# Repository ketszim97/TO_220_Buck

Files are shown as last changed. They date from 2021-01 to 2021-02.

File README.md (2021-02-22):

# TO_220_Buck
A buck converter drop in replacement for TO-220 LDOs

There are currently two versions:
- One for [78xx series LDOs](https://github.com/ketszim97/TO_220_Buck/tree/78xx)
- One for the [LM1117 LDO](https://github.com/ketszim97/TO_220_Buck/tree/LM1117)

They are both configured for 3.3V, but replacing R3 allows the output voltage to be set. 

|Output Voltage |  R3 Value |
| :---: | :---: |
| 1.5V | 86k6 |
| 1.8V | 60k4 |
| 2.5V | 35k7 |
| 3.3V | 24k3 |
| 5.0V | 14k3 |
| 12V | 5k36 |
| 24V | 2k61 |

Please take note of the pinouts as seen in the renders. 

I've been able to test basic functionality of both boards, but I am currently working on extended testing.

# [LM1117 Version](https://github.com/ketszim97/TO_220_Buck/tree/LM1117)
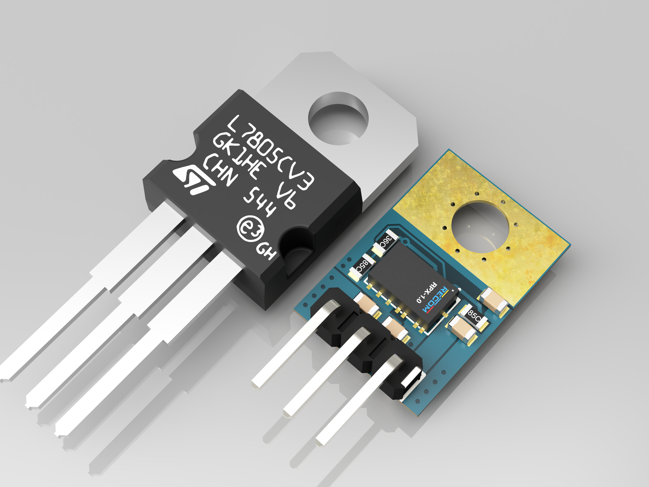
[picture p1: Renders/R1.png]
Fusion Render 1

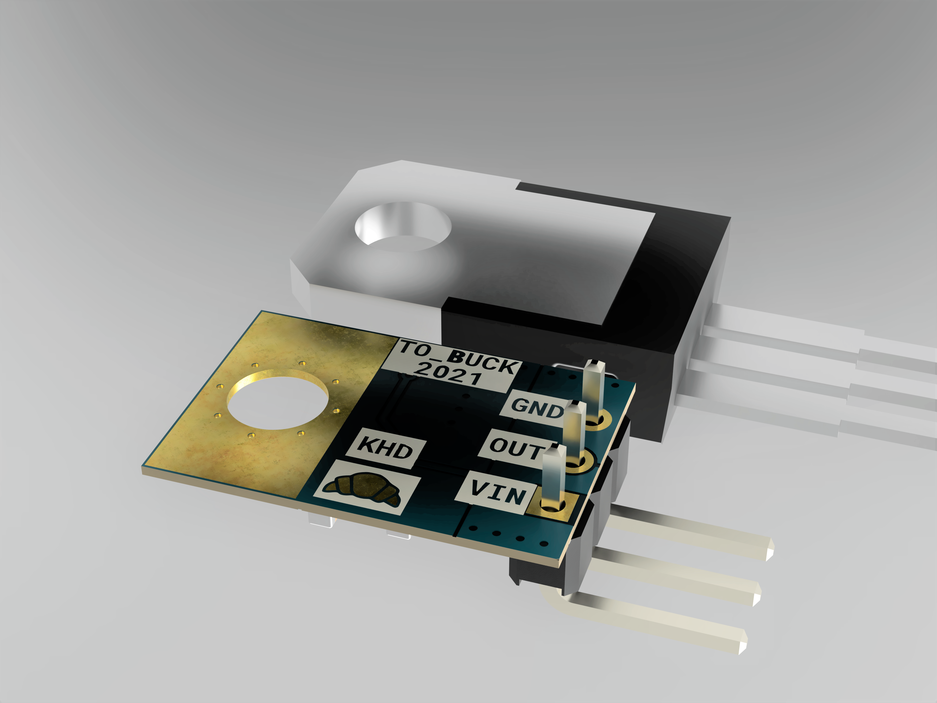
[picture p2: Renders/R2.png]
Fusion Render 2

Fusion Render 2

# [78xx Version](https://github.com/ketszim97/TO_220_Buck/tree/78xx)
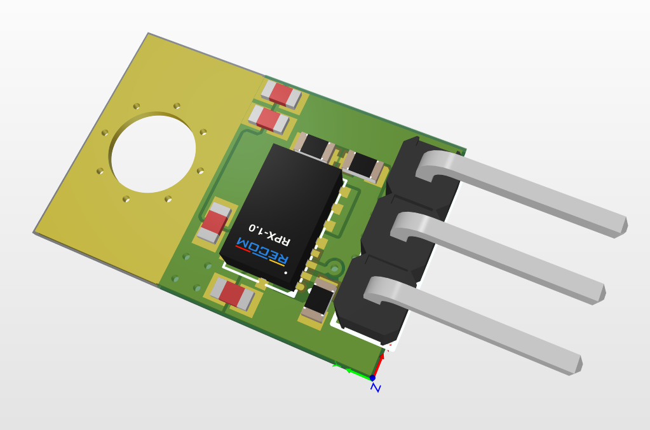
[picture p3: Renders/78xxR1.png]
Fusion Render 1

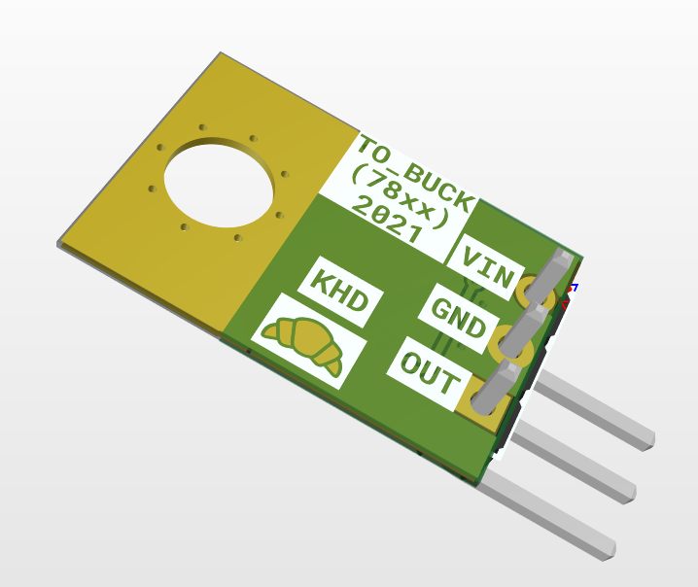
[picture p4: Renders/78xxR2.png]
Fusion Render 2


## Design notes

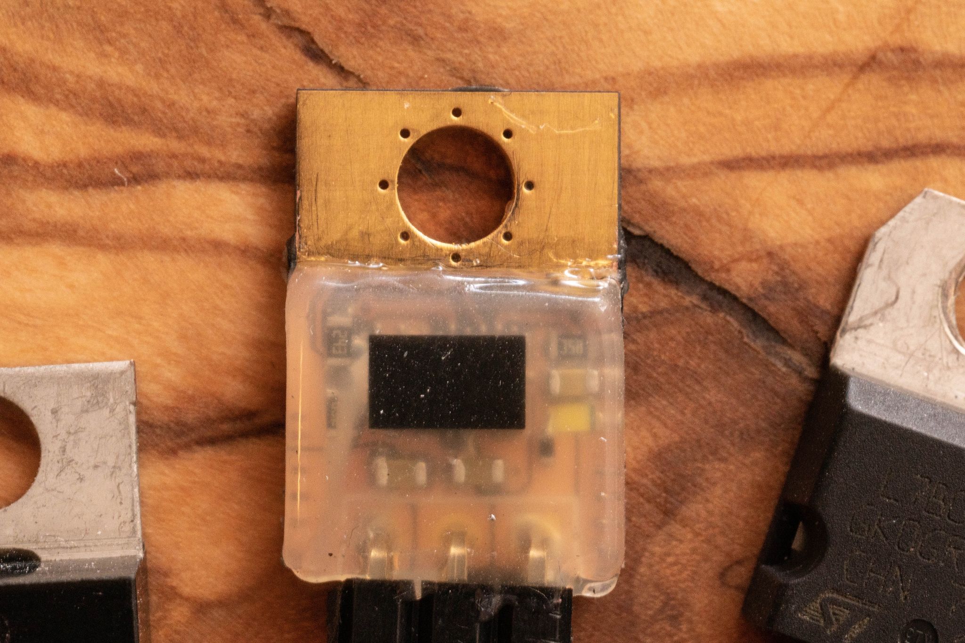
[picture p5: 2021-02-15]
Renders/Photos/149531206_1899397426883809_2604627616475933184_n.jpg

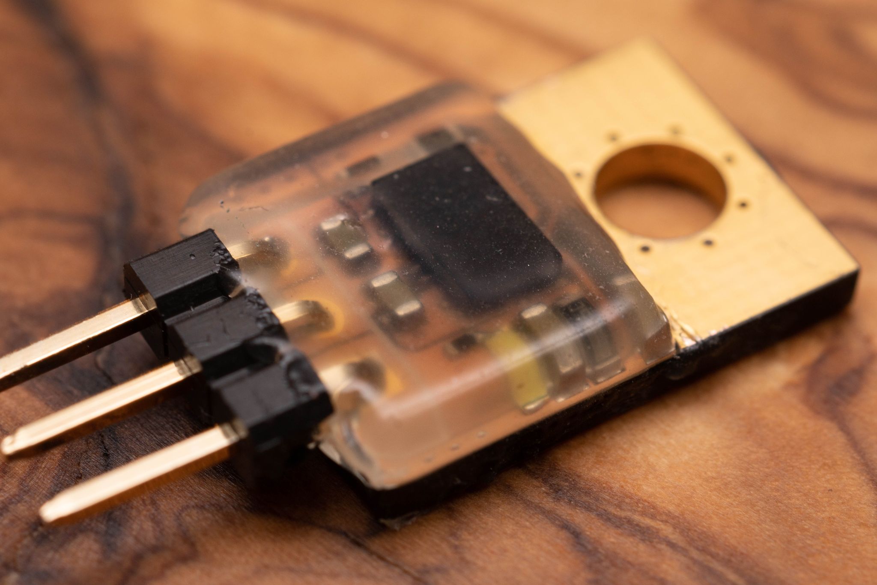
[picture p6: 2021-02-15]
Renders/Photos/149554997_872922463279282_781366280616274840_n.jpg

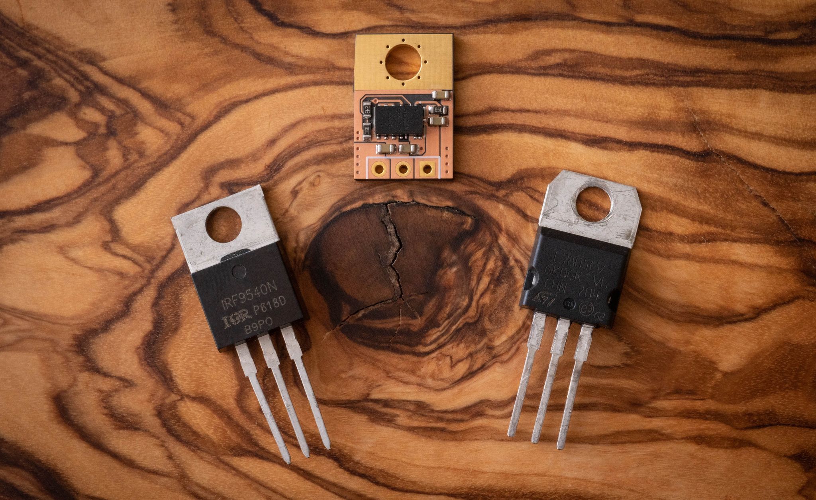
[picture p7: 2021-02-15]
Renders/Photos/150078867_431702474816400_1116094828932131625_n.jpg

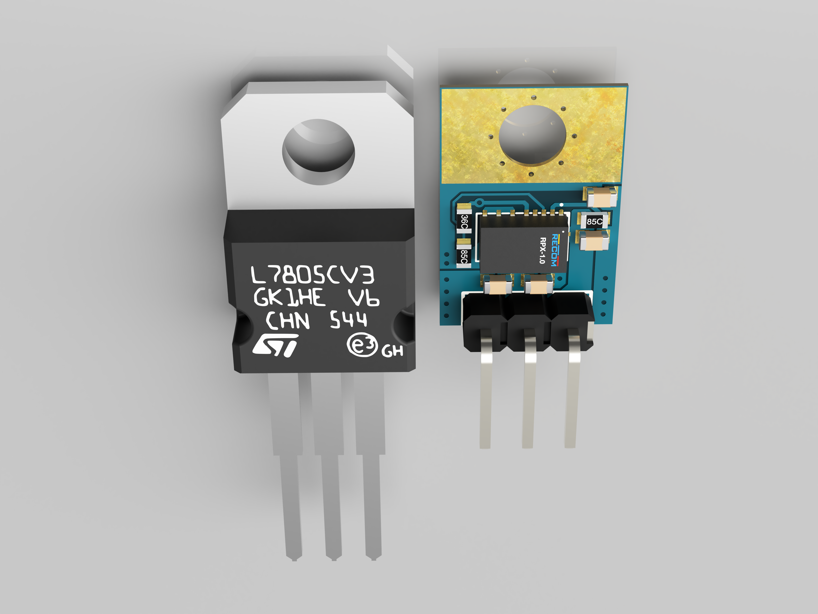
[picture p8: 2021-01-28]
Renders/R3.png

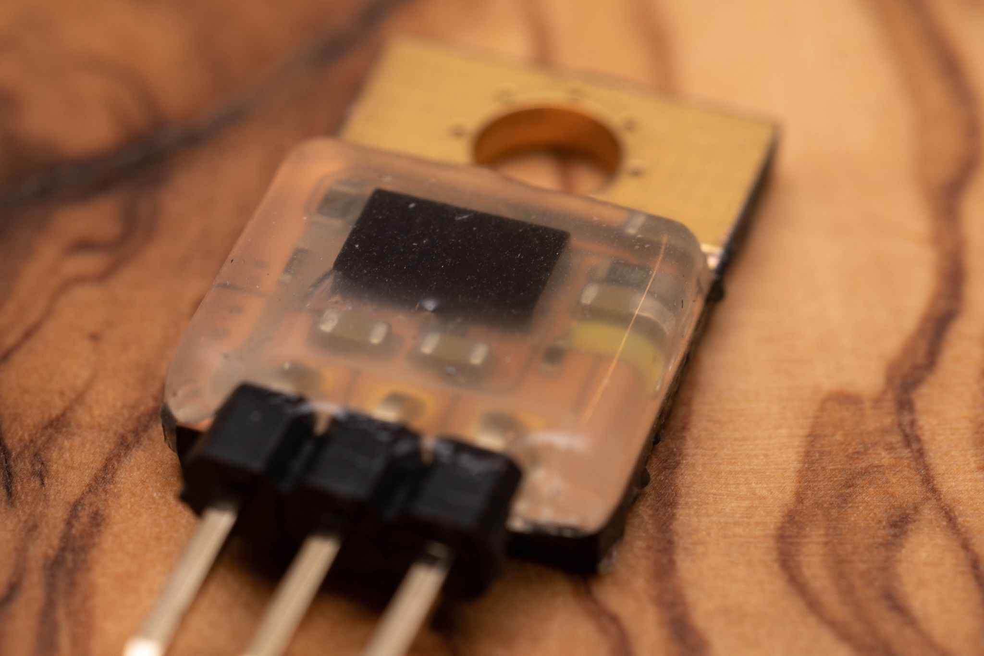
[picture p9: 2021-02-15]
Renders/Photos/149988475_1209948119421982_8042083003570764033_n.jpg

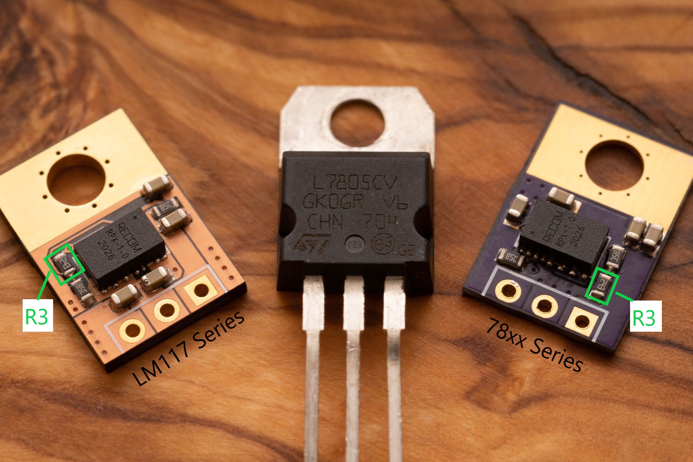
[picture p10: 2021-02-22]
Renders/Photos/R3 Annotation.jpg

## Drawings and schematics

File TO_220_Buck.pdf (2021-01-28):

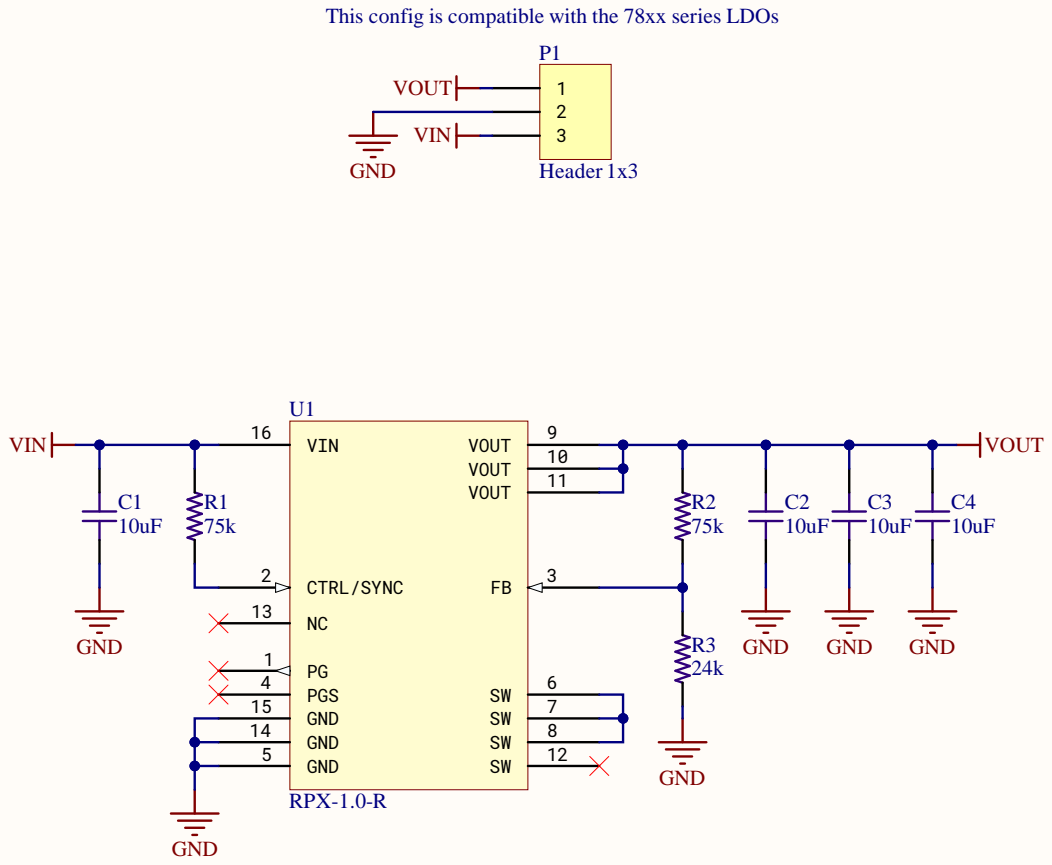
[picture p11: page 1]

This config is compatible with the 78xx series LDOs

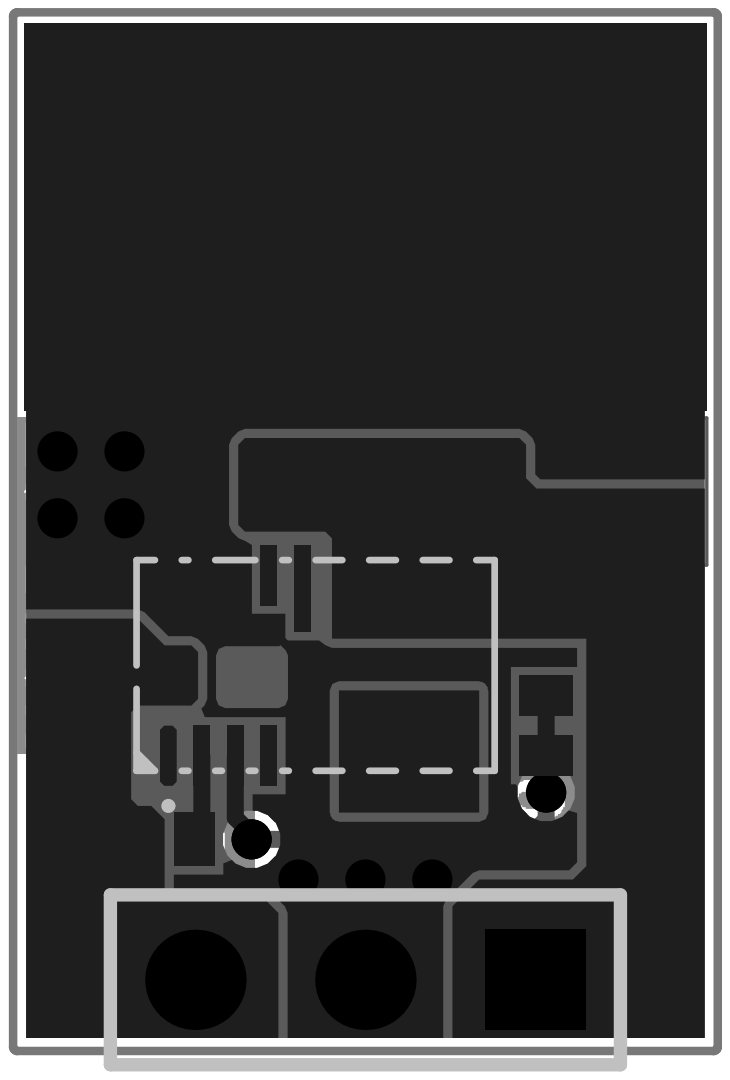
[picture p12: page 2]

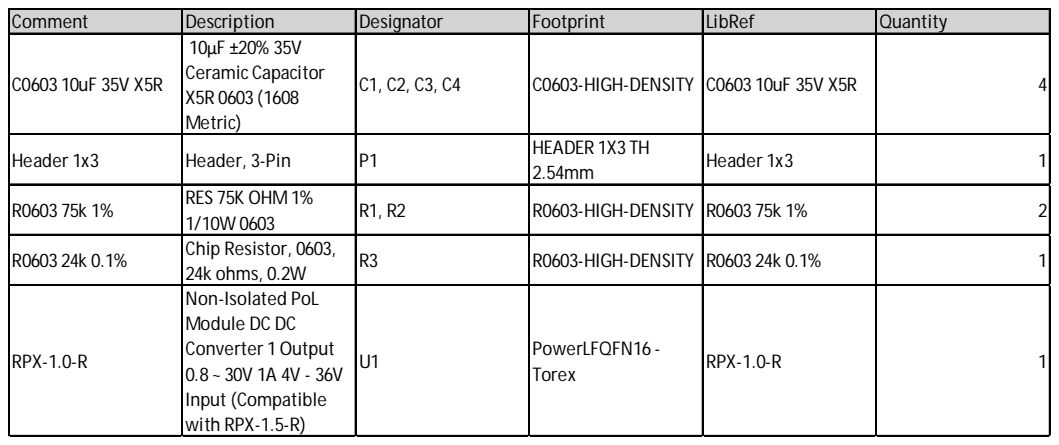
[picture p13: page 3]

Comment | Description | Designator | Footprint | LibRef | Quantity
C0603 10uF 35V X5R | 10µF ±20% 35V Ceramic Capacitor X5R 0603 (1608 Metric) | C1, C2, C3, C4 | C0603-HIGH-DENSITY | C0603 10uF 35V X5R | 4

Header 1x3 | Header, 3-Pin | P1 | HEADER 1X3 TH 2.54mm | Header 1x3 | 1

R0603 75k 1% | RES 75K OHM 1% 1/10W 0603 | R1, R2 | R0603-HIGH-DENSITY | R0603 75k 1% | 2

R0603 24k 0.1% | Chip Resistor, 0603, 24k ohms, 0.2W | R3 | R0603-HIGH-DENSITY | R0603 24k 0.1% | 1

RPX-1.0-R | Non-Isolated PoL Module DC DC Converter 1Output 0.8 ~ 30V 1A 4V - 36V Input (Compatible with RPX-1.5-R) | U1 | PowerLFQFN16 -Torex | RPX-1.0-R | 1

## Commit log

2021-01-28 Initil commit for LM1117 compatible version
    [TO_220_Buck.GBL, TO_220_Buck.GBO, TO_220_Buck.GBP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]
2021-01-28 78xx compatible version
    [TO_220_Buck.GBL, TO_220_Buck.GBO, TO_220_Buck.GBP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]
2021-02-15 Add PCB photos
